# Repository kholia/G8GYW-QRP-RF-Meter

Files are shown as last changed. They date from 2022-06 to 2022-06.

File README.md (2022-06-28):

#### PCB Renderings

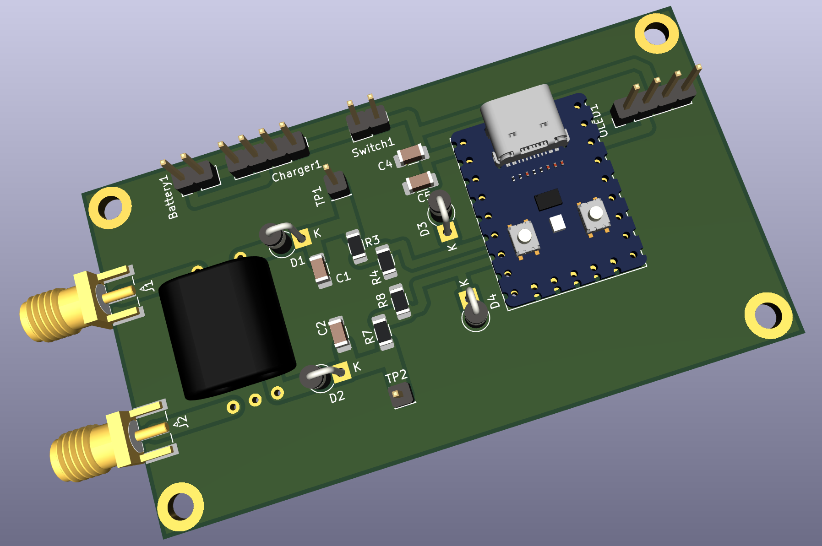
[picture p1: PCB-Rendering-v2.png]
PCB Rendering


#### BOM

Open `ibom.html` in your local browser.

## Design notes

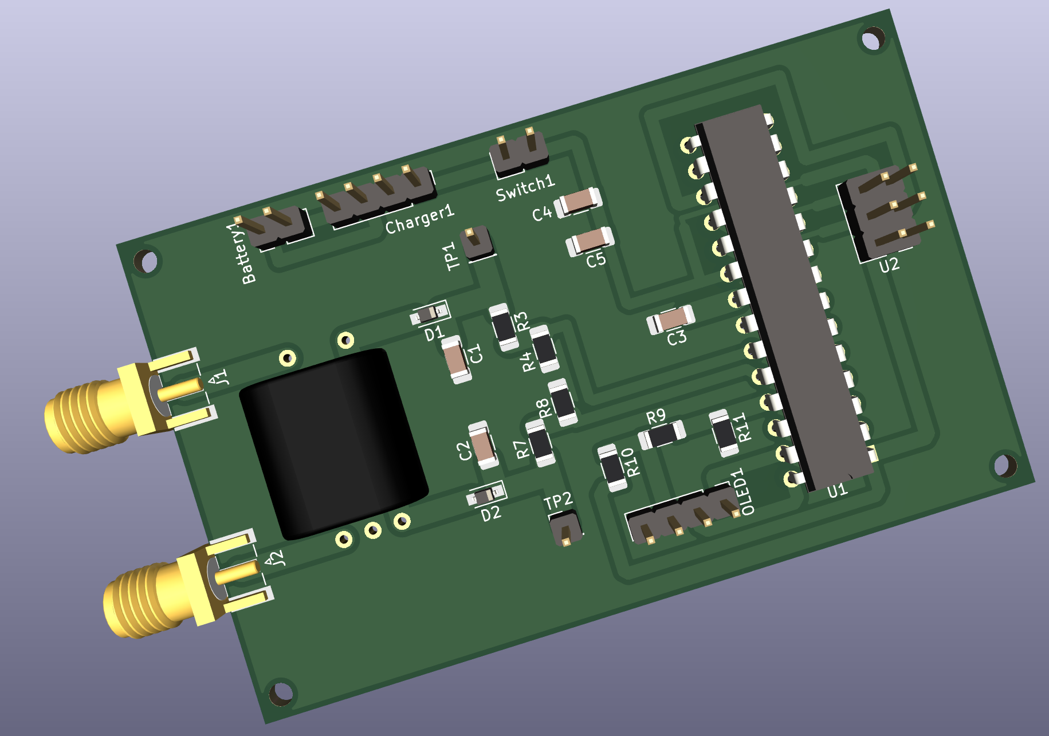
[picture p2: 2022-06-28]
PCB-Rendering.png

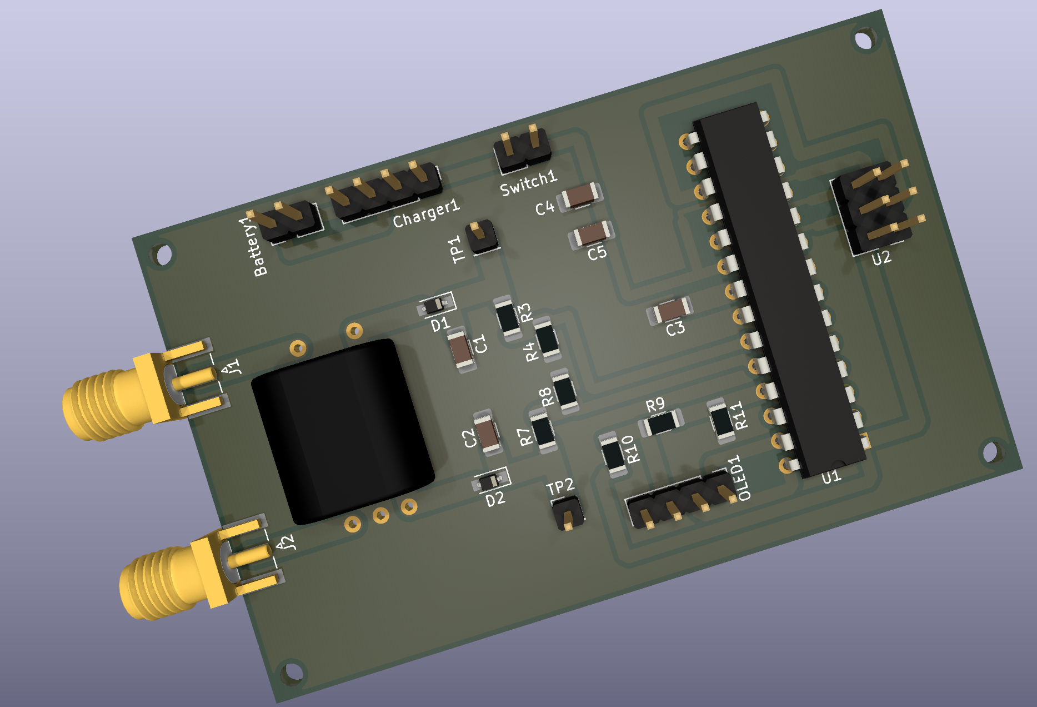
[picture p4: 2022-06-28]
PCB-Raytraced.png

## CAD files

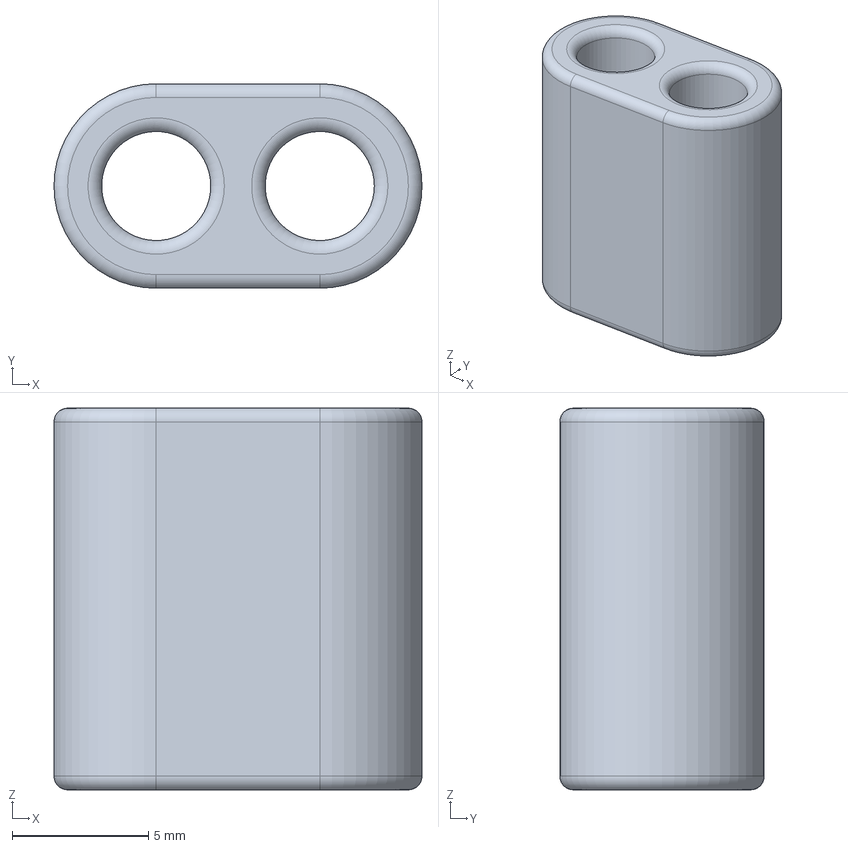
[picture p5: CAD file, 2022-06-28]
models/BN-43-202.step
13.5 x 7.50 x 14.0 mm

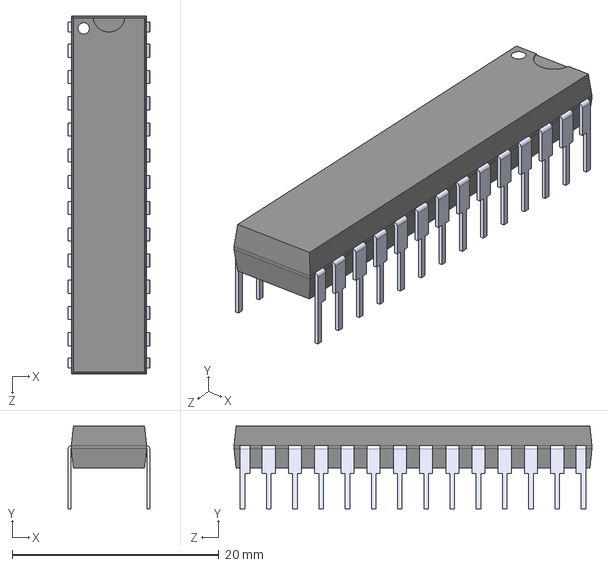
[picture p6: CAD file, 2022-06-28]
models/ATMEGA328-PU.step
7.90 x 8.00 x 34.7 mm

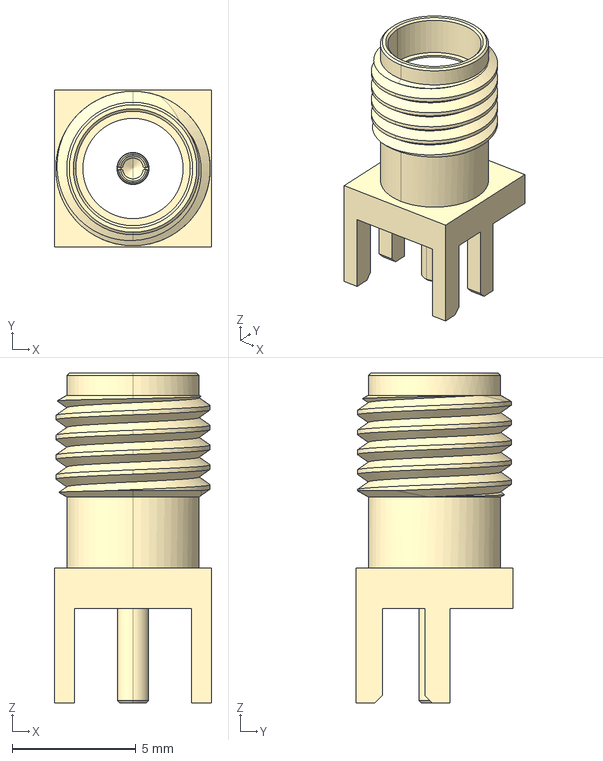
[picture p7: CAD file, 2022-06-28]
models/SAMTEC_SMA-J-P-H-ST-EM1.STEP
6.35 x 6.35 x 13.3 mm

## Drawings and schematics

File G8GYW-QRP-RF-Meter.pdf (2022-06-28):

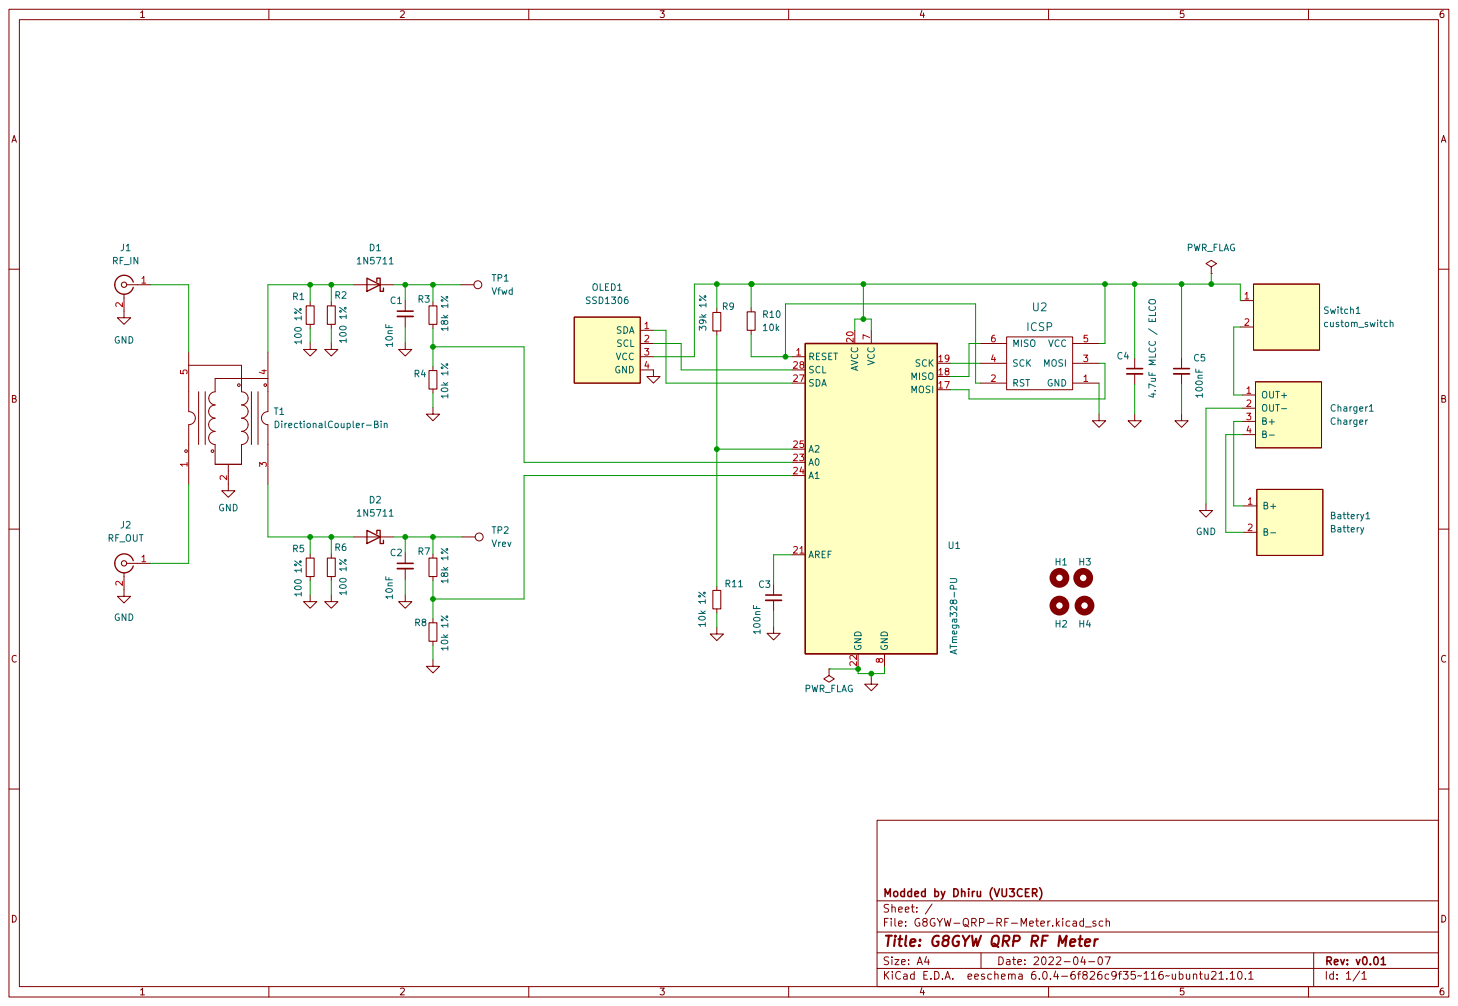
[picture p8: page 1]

File: G8GYW-QRP-RF-Meter.kicad_sch Sheet: / Modded by Dhiru (VU3CER)

Id: 1/1 Title: G8GYW QRP RF Meter

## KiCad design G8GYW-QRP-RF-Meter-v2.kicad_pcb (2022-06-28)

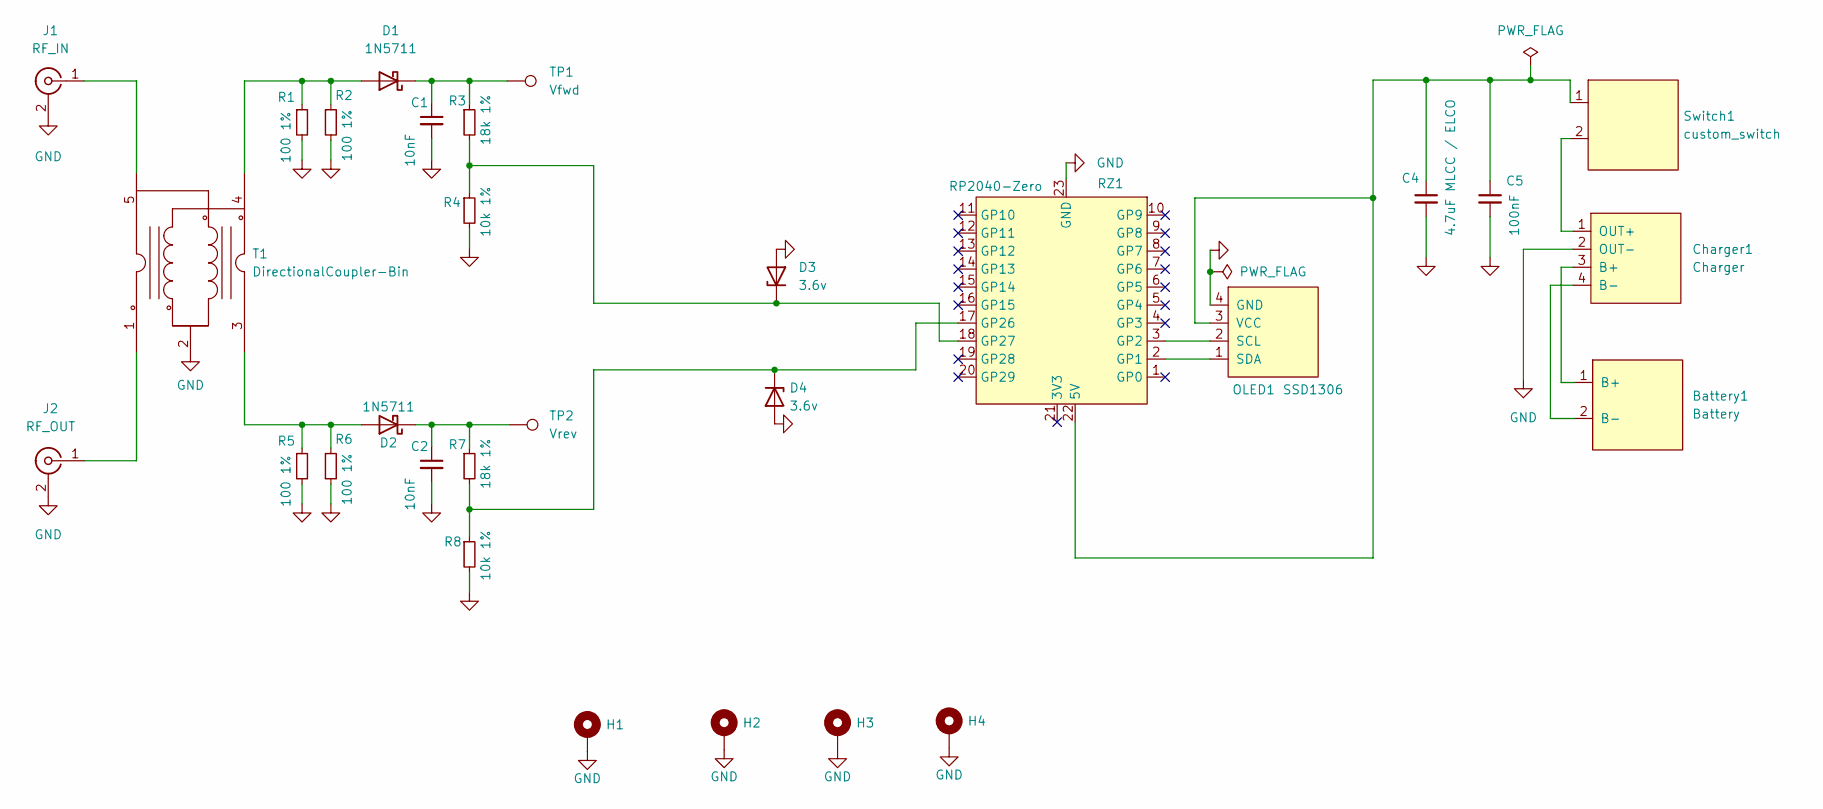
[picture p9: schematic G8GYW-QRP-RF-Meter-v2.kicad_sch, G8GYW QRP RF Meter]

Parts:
Battery1: Battery; PinHeader_1x02_P2.54mm_Vertical
C1, C2: 10nF; C_1206_3216Metric_Pad1.33x1.80mm_HandSolder
C4: 4.7uF MLCC / ELCO; C_1206_3216Metric_Pad1.33x1.80mm_HandSolder
C5: 100nF; C_1206_3216Metric_Pad1.33x1.80mm_HandSolder
Charger1: Charger; PinHeader_1x04_P2.54mm_Vertical
D1, D2: 1N5711; D_DO-41_SOD81_P2.54mm_Vertical_KathodeUp
D3, D4: 3.6v; D_DO-41_SOD81_P2.54mm_Vertical_KathodeUp
H1, H2, H3, H4: MountingHole_Pad; MountingHole_3.2mm_M3_ISO7380_Pad
J1: RF_IN; SMA_Samtec_SMA-J-P-X-ST-EM1_EdgeMount
J2: RF_OUT; SMA_Samtec_SMA-J-P-X-ST-EM1_EdgeMount
OLED1: SSD1306; PinHeader_1x04_P2.54mm_Vertical
R1, R2, R5, R6: 100 1%; R_1206_3216Metric_Pad1.30x1.75mm_HandSolder
R3, R7: 18k 1%; R_1206_3216Metric_Pad1.30x1.75mm_HandSolder
R4, R8: 10k 1%; R_1206_3216Metric_Pad1.30x1.75mm_HandSolder
RZ1: RP2040-Zero
Switch1: custom_switch; PinHeader_1x02_P2.54mm_Vertical
T1: DirectionalCoupler-Bin; BN-43-202-5P
TP1: Vfwd; PinHeader_1x01_P2.54mm_Vertical
TP2: Vrev; PinHeader_1x01_P2.54mm_Vertical

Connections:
GND: C1.2, C2.2, C4.2, C5.2, Charger1.2 (OUT-), D3.2 (A), D4.2 (A), H1.1, H2.1, H3.1, H4.1, J1.2 (Ext), J2.2 (Ext), OLED1.4 (GND), R1.2, R2.2, R4.2, R5.2, R6.2, R8.2, RZ1.23 (GND), T1.2
unnamed: Battery1.1 (B+), Charger1.3 (B+)
unnamed: Battery1.2 (B-), Charger1.4 (B-)
unnamed: C1.1, D1.1 (K), R3.1, TP1.1
unnamed: C2.1, D2.1 (K), R7.1, TP2.1
unnamed: C4.1, C5.1, OLED1.3 (VCC), RZ1.22 (5V), Switch1.1
unnamed: Charger1.1 (OUT+), Switch1.2
unnamed: D1.2 (A), R1.1, R2.1, T1.4
unnamed: D2.2 (A), R5.1, R6.1, T1.3
unnamed: D3.1 (K), R3.2, R4.1, RZ1.18 (GP27)
unnamed: J1.1 (In), T1.5
unnamed: J2.1 (In), T1.1
unnamed: OLED1.1 (SDA), RZ1.2 (GP1)
unnamed: OLED1.2 (SCL), RZ1.3 (GP2)
unnamed: D4.1 (K), R7.2, R8.1, RZ1.17 (GP26)

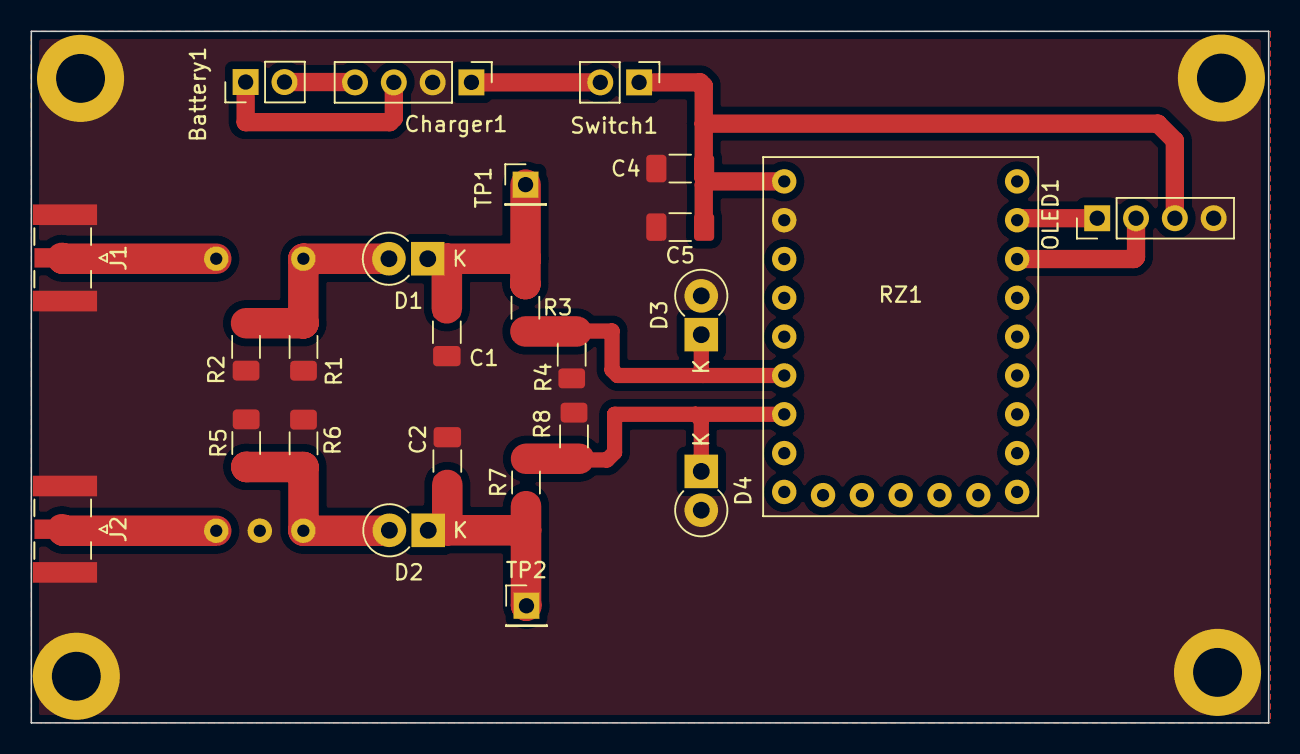
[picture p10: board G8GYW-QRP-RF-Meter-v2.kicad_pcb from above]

Board: 2 copper layers, 81.0 x 45.3 mm, 30 parts (0 on the bottom side), 15 nets.

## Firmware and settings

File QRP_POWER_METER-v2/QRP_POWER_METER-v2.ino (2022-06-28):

// https://g8gyw.github.io/
//
// Copyright (c) 2021 Mike G8GYW
//
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
// This program is designed to run on an Atmega328P with internal 8MHz clock and internal bandgap voltage reference.
// It takes the outputs from a Stockton bridge using a 10:1 transformer turns ratio and 1N5711 Scottky diodes,
// applies calibration factors then calculates and displays the average forward power, VSWR and battery voltage.

// ATMEGA FUSE VALUES
// E:FF   H:D7   L:E2

#include <Wire.h>
#include <Adafruit_SSD1306.h>
#include "Filter.h"

#define VERSION   "v1.06"
#define SCREEN_WIDTH 128 // OLED display width, in pixels
#define SCREEN_HEIGHT 64 // OLED display height, in pixels
#define OLED_RESET    -1 // Reset pin # (or -1 if sharing Arduino reset pin)

Adafruit_SSD1306 display(SCREEN_WIDTH, SCREEN_HEIGHT, &Wire, OLED_RESET);

// DEFINE VARIABLES

float Vfwd;   // Forward voltage
float Vrev;   // Reverse voltage
float Pfwd;   // Forward power
float Prev;   // Reverse power
float SWR;    // VSWR
float Gamma;  // Reflection coefficient
float Vbat;   // Battery voltage

// CALIBRATION FACTORS
// The tolerance on the Atmega328P's internal voltage reference is 1.0 to 1.2 Volts.
// The actual voltage should be measured on pin 21 and entered below.

// The response of the 1N5711 diodes follows a curve represented by the equation:
// Pfwd = aVfwd^2 + bVfwd (and the same for Prev and Vrev)
// where a and b are constants determined by plotting Power In vs Vfwd and performing a curve fit.
// An excellent tool for this can be found at https://veusz.github.io/
// The values of a and b below can be adjusted if necessary to improve accuracy (try adjusting b first).

const float IntRef = 1.1;
const float a = 1.0;
const float b = 0.75;

// FUNCTIONS TO CALCULATE FORWARD AND REVERSE POWER

float CalculatePfwd ()
{
  float Vadc0 = analogRead(A0); // Read ADC0 (pin 23)
  Vadc0 = constrain(Vadc0, 1, 1023); // Prevent divide-by-zero when calculating Gamma
  Vfwd = 2.8 * ((Vadc0 + 0.5) * IntRef / 1024); // Scaled up by R3 & R4
  Pfwd = a * sq(Vfwd) + b * Vfwd;
  return Pfwd;
}

float CalculateSWR ()
{
  float Vadc1 = analogRead(A1); // Read ADC1 (pin 24)
  Vrev = 2.8 * ((Vadc1 + 0.5) * IntRef / 1024); // Scaled up by R7 & R8
  Prev = a * sq(Vrev) + b * Vrev;
  if (Prev < 0.01)
  { //exclude residual values
    Prev = 0;
  }
  Gamma = sqrt(Prev / Pfwd); // Calculate reflection coefficient

  SWR = (1 + Gamma) / (1 - Gamma);
  SWR = constrain(SWR, 1, 99.9);
  return SWR;
}

// ADC FILTER
// A recursive filter removes jitter from the readings using the MegunoLINK filter library:
// https://www.megunolink.com/documentation/arduino-libraries/exponential-filter/

// Create new exponential filters with a weight of 90 and initial value of 0
// Adjust these values as required for a stable display

ExponentialFilter<float> FilteredPfwd(50, 0);
ExponentialFilter<float> FilteredVSWR(50, 0);

void setup()
{
  ADCSRA &= ~(bit (ADPS0) | bit (ADPS1) | bit (ADPS2)); // Clear prescaler bits
  ADCSRA |= bit (ADPS1) | bit (ADPS2);                  // Set prescaler to 64

  // Enable the internal voltage reference and disable unused digital buffers
  analogReference (INTERNAL);
  bitSet (DIDR0, ADC3D);
  bitSet (DIDR0, ADC4D);
  bitSet (DIDR0, ADC5D);

  analogRead (A2);  // Read ADC2
  delay (500); // Allow ADC to settle
  float Vpot = analogRead (A2); // Read ADC again
  Vbat = 4.9 * ((Vpot + 0.5) * IntRef / 1024); // Calculate battery voltage scaled by R9 & R10

  // Display startup screen
  Serial.begin(9600);
  display.begin(SSD1306_SWITCHCAPVCC, 0x3C);  //Initialize with the I2C address 0x3C.
  display.clearDisplay();
  display.setTextSize(1);
  display.setTextColor(WHITE);
  display.setCursor(0, 0);
  display.print("   POWER/SWR METER   ");
  display.setCursor(0, 16);
  display.print("    12 Watts maximum    ");
  display.setCursor(0, 32);
  display.print("Battery volts = ");
  display.print(Vbat);
  display.setCursor(0, 48);
  display.print("--------");
  display.print(VERSION);
  display.print("--------");
  display.display();
  delay(5000);        // delay 5 seconds

}

void loop()
{
  float Power = CalculatePfwd(); // Get new value of forward power
  FilteredPfwd.Filter(Power); // Apply filter to new value
  float SmoothPower = FilteredPfwd.Current(); // Return current value of filter output

  float VSWR = CalculateSWR(); // Get new value of VSWR
  FilteredVSWR.Filter(VSWR); // Apply filter to new value
  float SmoothVSWR = FilteredVSWR.Current(); // Return current value of filter output

  // Display Power and VSWR
  display.clearDisplay();
  display.setTextSize(2);
  display.setCursor (12, 12);
  display.print("PWR: ");
  display.setCursor (60, 12);
  display.print(SmoothPower, 1); // Display forward power to one decimal place
  display.print("W");
  display.setCursor (12, 36);
  display.print("SWR: ");
  display.setCursor (60, 36);
  if (Pfwd < 0.01)
  { display.print("**.*"); // Blank invalid readings
  }
  else {
    display.print(SmoothVSWR, 1); // Display VSWR to one decimal place
  }
  display.display();

}
